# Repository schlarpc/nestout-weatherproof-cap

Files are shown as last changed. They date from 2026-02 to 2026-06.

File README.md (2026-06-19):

# Nestout 15000mAh — Weatherproof Cable Passthrough Cap

A 3D-printed replacement cap for the Nestout 15000mAh battery bank that integrates a McMaster-Carr cable gland, allowing a USB cable to pass into the sealed battery while maintaining water resistance.

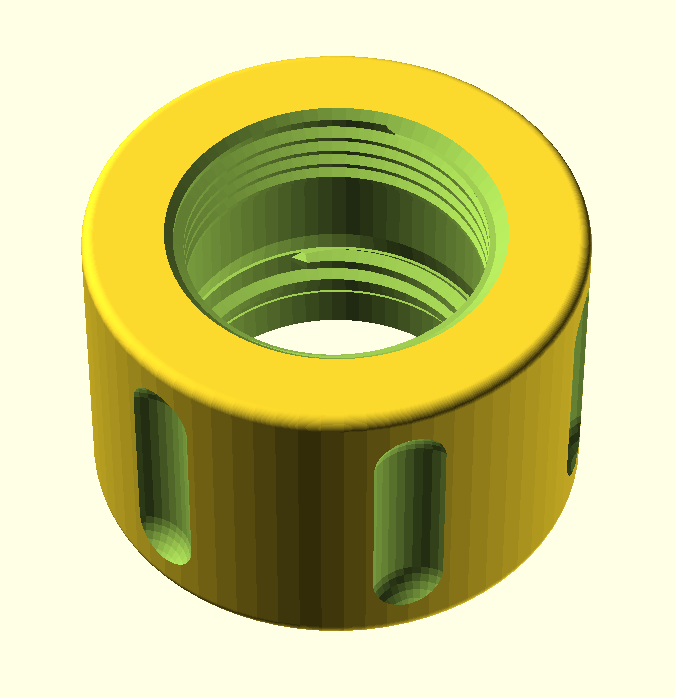
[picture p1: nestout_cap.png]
Render of the adapter cap


## Built Result

The printed cap installed on a Nestout 15000mAh battery with the McMaster 5302N121 cord grip threaded into the top and a USB cable passing through into the sealed body:

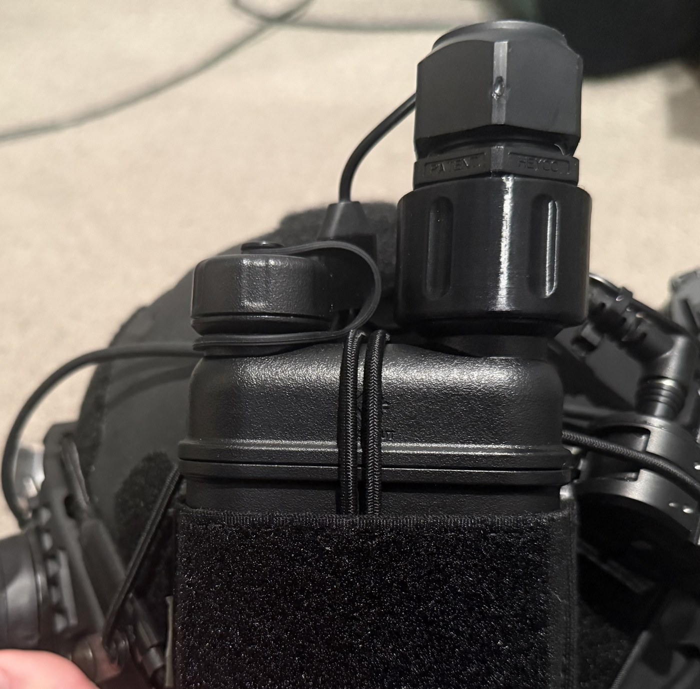
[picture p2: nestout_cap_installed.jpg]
Printed cap with cord grip installed on the battery


Powering a helmet-mounted setup in the field — the weatherproofed battery routes its cable out through the gland with the seal intact:

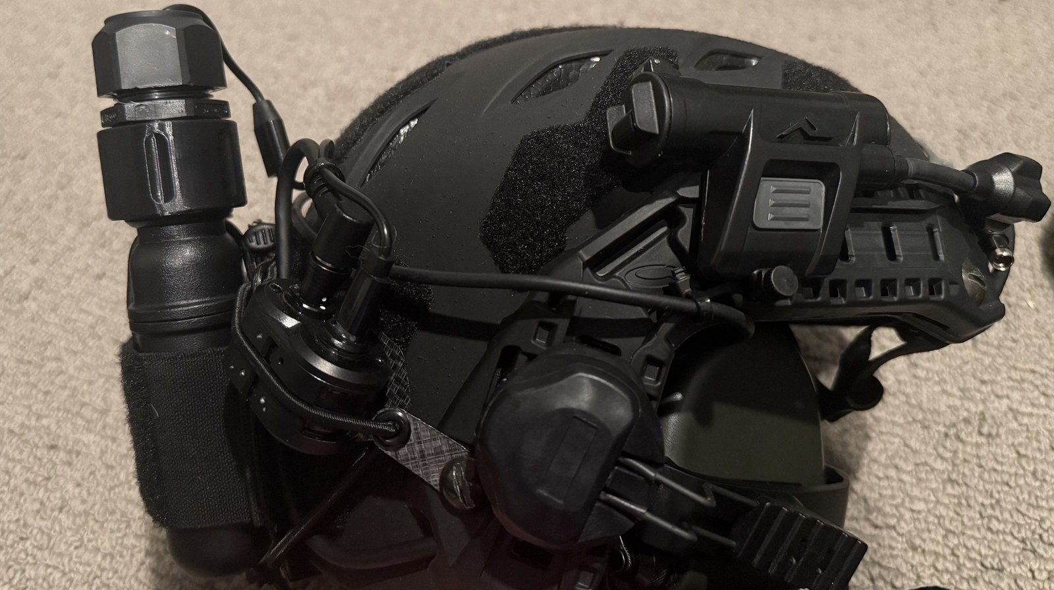
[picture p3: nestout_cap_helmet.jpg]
Battery with weatherproof cap mounted on a helmet rig


## Parts

| Part | Source | Qty |
|---|---|-----|
| [Nestout 15000mAh battery](https://nestout.com/products/outdoor-portable-battery-15000mah) | — | 1 |
| [McMaster 5302N121 cord grip](https://www.mcmaster.com/5302N121/) | mcmaster.com | 1 |
| 3D-printed adapter cap | This repo | 1 |
| Self-fusing silicone tape | Amazon / hardware store | 1 roll |

## How It Works

The cap is a thread adapter with two sets of internal threads:

- **Bottom:** Nestout proprietary threads (25.5mm major diameter, 2.2mm pitch, trapezoidal) mate with the battery body's male threads. The battery's O-ring seals against the cap's smooth bore below the threads.
- **Top:** Standard M25x1.5 threads accept the McMaster 5302N121 gland shaft directly. The gland's hex body sits on the cap's top face.

The cable passes through the gland, through the cap bore, and down into the battery's port well. The bore is wide enough for a USB cable to route with a gentle bend to reach the port. Use a right-angle USB adapter if needed.

### Cross-Section

```
                    ┌─ Compression cap
                    │  ┌─ Split rubber bung (around cable)
                    │  │
            ╔═══════╧══╧═══════╗
            ║   Gland hex body ║ ← Sits on cap top surface
            ╠═══════╤═══╤══════╣
            ║  M25×1.5 threads ║ ← 8mm deep
    ┌───────╫───────┤   ├──────╫───────┐
    │       ║  Shaft clearance ║       │  3D-printed
    │       ╠───────┤   ├──────╣       │  adapter cap
    │       ║  Nestout threads ║       │  (PETG)
    │       ║  (~2 turns)      ║       │
    │       ╠───────┤   ├──────╣       │
    │       ║  Smooth bore     ║       │
    │       ║  (O-ring zone)   ║       │
    └───────╫───────┤   ├──────╫───────┘
            ║  ●═O-ring═●      ║ ← Lives on battery body
            ╠═══════╧═══╧══════╣
            ║   Battery body   ║
            ║   (USB ports)    ║
            ╚══════════════════╝
```

### Sealing

1. **Battery to cap:** The O-ring on the battery body presses against the cap's smooth internal bore — same principle as the stock cap.
2. **Cap to gland:** M25 threads provide mechanical retention. Wrap 2-3 turns of PTFE tape on the gland shaft threads before installing for a watertight seal.
3. **Gland to cable:** The cord grip's split rubber bung and compression cap handle this (IP68-rated). The 5302N121 fits 5.3-8.5mm cable OD. Most USB cables are 4-4.5mm — wrap a few layers of self-fusing silicone tape around the cable at the seal point to build up the diameter.
4. **USB plug:** Apply dielectric grease to the USB connector before plugging in. This displaces moisture from the contacts and prevents corrosion if any water does get inside.

## Printing

### Requirements

- [OpenSCAD](https://openscad.org/)
- [BOSL2 library](https://github.com/BelfrySCAD/BOSL2) — install via OpenSCAD's Library Manager

### Settings

| Setting | Value |
|---|---|
| Material | PETG or ASA (not PLA) |
| Layer height | 0.12-0.15mm |
| Infill | 100% |
| Walls/perimeters | 4+ |
| Orientation | Threaded end down on build plate |
| Supports | None |

PLA is too brittle for coarse threads with only ~2 turns of engagement, and softens in heat (a black battery in direct sun easily exceeds 60C).

### Tuning

If the cap is too tight on the battery, increase `nestout_slop` (try 0.25-0.30). If too loose, decrease it (try 0.15). Same idea for `m25_slop` and the gland fit.

## Dimensions

| Parameter | Value |
|---|---|
| Cap outer diameter | 40mm |
| Cap total height | ~26mm |
| Nestout thread major dia. | 25.5mm |
| Nestout pitch | 2.2mm |
| Smooth bore ID | 25.9mm |
| Battery engagement depth | 10mm |
| M25 thread depth | 8mm |

## License

This project is provided as-is with no warranty. Use at your own risk.

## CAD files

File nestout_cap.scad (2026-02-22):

// ================================================================
// Nestout 15000mAh — Waterproof Cable Passthrough Cap
// For McMaster-Carr 5302N121 Wraparound Cord Grip (M25)
// ================================================================
//
// REQUIRES: BOSL2 library for thread generation
//   Install: https://github.com/BelfrySCAD/BOSL2
//   Or in OpenSCAD: File → Library Manager → Install BOSL2
//
// ASSEMBLY (bottom to top):
//   1. Gland shaft threads into M25 hole from above
//   2. Gland hex body/flange sits on cap top surface
//   3. (Optional) outer locknut above gland hex for extra hold
//   4. Cap threads onto Nestout battery (~2 turns)
//   5. Split rubber bung wraps around cable
//   6. Gland compression cap tightens to seal cable
//
// PRINT SETTINGS:
//   Material: PETG or ASA (NO PLA — too brittle for threads)
//   Layer height: 0.12–0.15mm
//   Infill: 100% (small part, just do it)
//   Orientation: Open/threaded end DOWN on build plate
//   Supports: None needed
//   Walls/perimeters: 4+ for thread strength
//
// ================================================================

include <BOSL2/std.scad>
include <BOSL2/threading.scad>

// ========================
// MEASURED VALUES — Nestout 15000mAh battery body
// ========================

// Nestout battery thread (male threads on battery body)
nestout_thread_id  = 25.5;   // Male thread major diameter (crest to crest)
nestout_pitch      = 2.2;    // Thread pitch (trapezoidal)
nestout_engagement = 10.0;   // Total depth cap screws onto battery
nestout_thread_zone = 5.0;   // Upper 5mm of engagement has threads
nestout_smooth_zone = 5.0;   // Lower 5mm is smooth (O-ring contact)

// ========================
// McMASTER GLAND (5302N121) — from drawing
// ========================

m25_pitch          = 1.5;    // Standard M25 fine pitch
gland_shaft_length = 13.2;   // 0.52" total shaft length

// ========================
// DESIGN PARAMETERS — tune these for fit
// ========================

// Thread tolerances (per side)
nestout_slop   = 0.20;       // Clearance on Nestout threads
m25_slop       = 0.15;       // Clearance on M25 threads

// Overall geometry
cap_od           = 40.0;     // Outer diameter (clears 33mm gland hex body)
top_plate_height = 8.0;      // M25 thread depth
transition_height = 2.0;     // Taper from Nestout bore to shaft clearance bore

// Shaft clearance — the gland shaft protrudes below the M25 threads.
// Cable routes straight from shaft exit to the USB port below.
shaft_clearance  = 1.0;      // Gap below shaft tip (mm)
cavity_height    = gland_shaft_length - top_plate_height + shaft_clearance;
                              // ≈6.2mm — just clears the unengaged shaft
cavity_id        = 26.0;     // Interior bore — must clear M25 shaft OD (~25mm)

// Exterior grip profile
groove_count     = 6;        // Finger grooves around circumference
groove_depth     = 1.5;      // How deep grooves cut into surface (mm)
groove_cutter_r  = 4.0;      // Cross-section radius of each groove
top_fillet       = 1.0;      // Exterior top edge rounding
bottom_fillet    = 1.5;      // Exterior bottom edge rounding

bottom_chamfer   = 1.5;      // Bore chamfer on bottom (thread lead-in)
top_chamfer      = 1.0;      // Bore chamfer on top (gland thread lead-in)
thread_angle     = 29;       // Thread flank angle for Nestout threads

// ========================
// DERIVED DIMENSIONS
// ========================

smooth_bore_id = nestout_thread_id + nestout_slop * 2;
m25_bore_id    = 25.0;  // Nominal M25
total_height   = nestout_engagement + transition_height + cavity_height + top_plate_height;

// Sanity checks
echo(str("── Cap Dimensions ──"));
echo(str("  Total height: ", total_height, "mm"));
echo(str("  Outer diameter: ", cap_od, "mm"));
echo(str("  Smooth bore ID: ", smooth_bore_id, "mm"));
echo(str("  Cavity height: ", cavity_height, "mm"));
echo(str("  Shaft protrusion into cavity: ",
    gland_shaft_length - top_plate_height, "mm"));
echo(str("  Clearance below shaft: ", shaft_clearance, "mm"));
echo(str("  Nestout thread zone: ", nestout_thread_zone, "mm @ ", nestout_pitch, "mm pitch"));
echo(str("  M25 thread depth: ", top_plate_height, "mm @ ", m25_pitch, "mm pitch"));
echo(str("  Nestout thread turns: ", nestout_thread_zone / nestout_pitch));
echo(str("  M25 thread turns: ", top_plate_height / m25_pitch));

// ========================
// MODULES
// ========================

$fn = 72;  // Circle resolution — increase to 120 for final export

// --- Round exterior with finger-retention grooves ---
module cap_exterior(height) {
    // Grooves span the full exterior, inset from the fillet radii
    groove_bottom = bottom_fillet + 1;
    groove_top    = height - top_fillet - 1;

    difference() {
        // Round body with filleted top and bottom edges
        cyl(d = cap_od, h = height,
            rounding1 = bottom_fillet, rounding2 = top_fillet,
            anchor = BOTTOM);

        // Finger-retention grooves — rounded channels for secure grip
        for (i = [0 : groove_count - 1])
            rotate([0, 0, i * 360 / groove_count])
                translate([cap_od/2 - groove_depth + groove_cutter_r, 0, 0])
                    hull() {
                        translate([0, 0, groove_bottom + groove_cutter_r])
                            sphere(r = groove_cutter_r, $fn = 36);
                        translate([0, 0, groove_top - groove_cutter_r])
                            sphere(r = groove_cutter_r, $fn = 36);
                    }
    }
}

// ========================
// MAIN: FULL CAP
// ========================

module cap_body() {
    $slop = 0;  // We handle slop per-thread below

    difference() {
        // ── Solid exterior ──
        cap_exterior(total_height);

        // ── Zone 1: Smooth bore (bottom 5mm) ──
        // O-ring on battery body seals against this surface.
        // Must be smooth and dimensionally accurate.
        translate([0, 0, -0.01]) {
            cylinder(d = smooth_bore_id, h = nestout_smooth_zone + 0.02);

            // Lead-in chamfer at very bottom
            cylinder(
                d1 = smooth_bore_id + bottom_chamfer * 2,
                d2 = smooth_bore_id,
                h  = bottom_chamfer
            );
        }

        // ── Zone 2: Nestout threaded bore (upper 5mm of engagement) ──
        // Trapezoidal thread, coarse pitch, ~2 turns
        translate([0, 0, nestout_smooth_zone]) {
            $slop = nestout_slop;
            trapezoidal_threaded_rod(
                d       = nestout_thread_id,
                l       = nestout_thread_zone + 0.1,
                pitch   = nestout_pitch,
                thread_angle = thread_angle,
                internal = true,
                anchor   = BOTTOM
            );
        }

        // ── Zone 3: Transition (short taper from thread bore to cavity) ──
        translate([0, 0, nestout_engagement - 0.01])
            cylinder(
                d1 = smooth_bore_id + 1.0,
                d2 = cavity_id,
                h  = transition_height + 0.02
            );

        // ── Zone 4: Shaft clearance (gland shaft protrudes here) ──
        translate([0, 0, nestout_engagement + transition_height - 0.01])
            cylinder(
                d = cavity_id,
                h = cavity_height + 0.02
            );

        // ── Zone 5: M25 × 1.5 threaded bore (top plate) ──
        // Gland shaft threads into this from above
        translate([0, 0, nestout_engagement + transition_height + cavity_height - 0.01]) {
            $slop = m25_slop;
            threaded_rod(
                d        = m25_bore_id,
                l        = top_plate_height + 0.02,
                pitch    = m25_pitch,
                internal = true,
                anchor   = BOTTOM
            );
        }

        // ── Top chamfer (thread lead-in for gland) ──
        translate([0, 0, total_height - top_chamfer])
            cylinder(
                d1 = m25_bore_id,
                d2 = m25_bore_id + top_chamfer * 2,
                h  = top_chamfer + 0.01
            );
    }
}


// ========================
// CROSS-SECTION VIEW (for visualization)
// ========================

module cross_section() {
    difference() {
        cap_body();
        translate([0, -100, -1])
            cube([200, 200, 200]);
    }
}


// ========================
// RENDER
// ========================

cap_body();

//cross_section();

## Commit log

2026-02-22 Weatherproof cable passthrough cap for Nestout 15000mAh
    3D-printed replacement cap that integrates a McMaster-Carr 5302N121
    cord grip (M25) for running a USB cable into the sealed battery.
    Requires OpenSCAD with BOSL2.
    [nestout_cap.scad]
2026-06-18 Add real-world photos of built cap to README
    Add two photos demonstrating the finished 3D-printed cap: a close-up of
    the cord grip threaded into the cap on the battery, and the weatherproofed
    battery powering a helmet-mounted setup. All EXIF/identifying metadata
    stripped and images cropped for focus.
    Claude-Session: https://claude.ai/code/session_01RAdq3fbSLG2CYXKji6WbBw
